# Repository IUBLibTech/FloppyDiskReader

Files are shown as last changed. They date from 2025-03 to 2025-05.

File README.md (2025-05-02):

# FloppyDiskReader
Hardware and Software for the BDPL Floppy Disk Reader

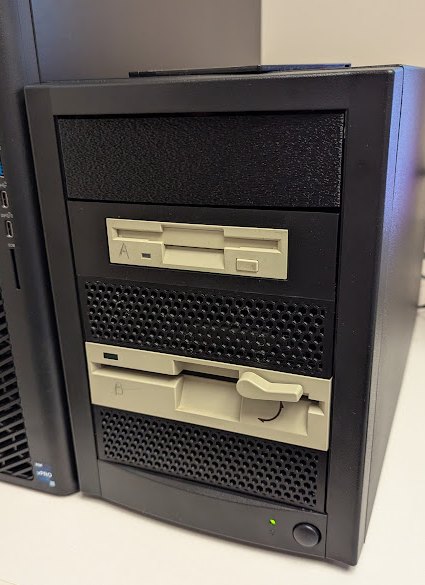
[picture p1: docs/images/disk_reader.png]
FloppyDisk Reader


## Hardware

The parts needed to build a reader from scratch are detailed in 
[Bill Of Materials](docs/bill_of_materials.md) and as of 2025 the cost is as little as $215 
using existing drives or $310 when buying eBay drives.

Assembly is described [here](docs/assembly.md)

## Software

The software is a Python / Qt application described [here](docs/software.md) 
and should run on most unix-y platforms, and maybe Windows (untested)

## License
Unless otherwise specified, all files are Copyright 2025 Trustees of Indiana 
University and are licensed under the Apache 2.0 License.

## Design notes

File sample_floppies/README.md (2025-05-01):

# Sample Floppy Disk Images
These are images which can be written to real floppies for testing.  

Each floppy is empty with the exception of some small sample data, such as
a basic program or text file.

The actual process will vary based on your hardware configuration, but
this should get you started.

The WRITE-ENABLE jumper must be present on the greaseweazle.

NOTE:  Writing 5.25" DD disks in an HD drive is not advised because of the
magnetic characteristics of the media.

Activate the Python Virtual Environment so the greaseweazle software is
in the path:

```
source .venv/bin/activate
```

Erase the disk.  If you are using a 40-track drive you will need to specify
which tracks to erase:

```
gw erase --drive A --tracks c=0-39
```

You may need to reset the greaseweazle if it's lost the index marker:

```
gw reset
```

Write the disk, specifying the format:
```
gw write --drive A --format commodore.1541 commodore_1541.d64
```

Generally the filenames are the greasweazle format name, substituting the '_'
with a '.'.

However, `ibm_1440_mac.img` is an `ibm.1440` formatted disk (flux-wise) but has
a Macintosh HFS filesystem on it, which is a normal configuration.

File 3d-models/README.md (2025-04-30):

# 3D models
These are the 3d models used for this project

* 5.25-bay-cover-vented.3mf - a drive bay blank
* Greaseweazle_Tray-HoleTest.stl - Test object to verify screws work
* Greaseweazle_Tray-Tray.{3mf,stl} - A full height 5.25" tray for mounting a V4.1 Greaseweazle
* Greaseweazle-4_Tray.* - A low-profile tray used to mount a V4 greaseweazle in the prototype
* USBC-Bulkhead - Mounting plate for USB C bulkhead connector

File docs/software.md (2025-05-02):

# Software

## Installation

Installation for this software should be pretty straightforward: it's a python
application running in a virtual environment.  It's been tested on Python 3.10
and 3.13

In the directory create the virtual environment and install the dependencies:

```
python3 -m venv .venv
. .venv/bin/activate
pip install -r requirements.txt
```

If successful, then the application can be started by running the `FloppyDiskReader`
shell script.

## Hardware Setup

Connect the floppy reader hardware to your computer using a USB cable.  When
the reader is powered on it will show up as a USB device called `generic greaseweazle`

You can verify this by running `lsusb`.

## Configuring the software

Copy the `FloppyDiskReader.conf.sample` file to `FloppyDiskReader.conf`.  That
is a basic configuration and should work in most cases where Drive A is a 3.5" 
HD floppy drive and B is a 5.25" HD drive.  

If necessary modify the configuration to meet your needs.  The file format is
YAML so aligning with spaces is important.

Linux permisions may block access to the greaseweazle.  To grant permission to
a user, become root and add them to the `dialout` group.  The user will need to
log out and log back in for the group changes to take effect.

## Running the software

The software can be started by running FloppyDiskReader.  If it is able to 
connect to the greaseweazle it will display the main window:

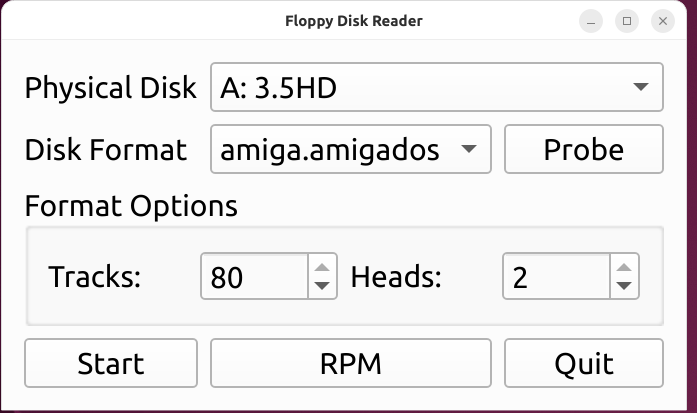
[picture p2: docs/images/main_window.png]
Main Window


The controls are:
* Physical disk selects which drive should be used for the read
* Disk format dropdown indicates what format should be read
* Probe button will try to determine the type of disk installed in the physical disk
* Format options allow control of number of tracks and number of heads
* Start button will start a new disk read
* RPM will test the RPM of the selected disk drive 
* Quit exits the program.

### Testing Disk RPM
Normally this isn't needed but it is a good way to verify the greaseweazle is
operating correctly.  Place a disk in the drive and hit the RPM button.  

If things are working it will show the expected RPM and the actual spin rate.

### Probing the format
Sometimes it's impossible to know what kind of disk you have.  The disk probe
will read track 1 of all of the configured format types and show you the ones
that it thinks are applicable.  The most likely candidate is the default:

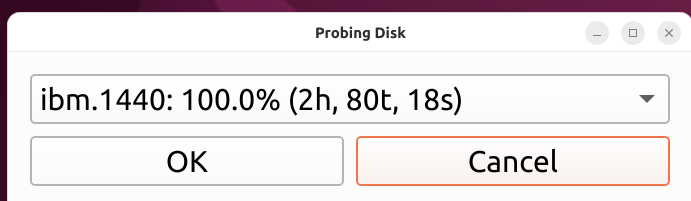
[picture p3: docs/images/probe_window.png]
Disk Probe


The percentage shown is the amount of expected sectors it was able to read. 
This number may be less than 100% if the disk has errors.

Some formats may be indistinguisable from each other.  For example, when probing
a 360K PC floppy (9 sectors per track), if the rare 320K (8 sectors per track)
floppy format is added to the list of formats to probe both will show 100%, 
but internally when using the 320K format it'll complain that it found an extra
sector on the track that was ignored.  The list is sorted by largest format
first, so that will likely be the correct format if there is ambiguity.

Select OK to use that format, cancel to manually select.

NOTE:  This is the physical format on the disk - the configuration of the
magnetic flux.  Macintosh 1.44M floppies will show up as `ibm.1440` because
the physical format is the same as the IBM 1.44M format even though the filesystem
data on there is different (HFS vs FAT16)

### Format Options
Normally this will not be needed unless you are wanting to read a partial disk.

One notable exception to this is for the `commodore.1541` format.  The format
allows for 40 tracks but the normal format was 35.  When reading these disks
one would adjust it down to 35 tracks.

### Reading a disk
Once the drive and format are selected and any adjustments are made to the format,
then pressing the Start button will read the disk.

A file dialog will allow you to choose where to save the disk image and the 
extension should be automatically selected.  Once selected, a read window
will pop up:

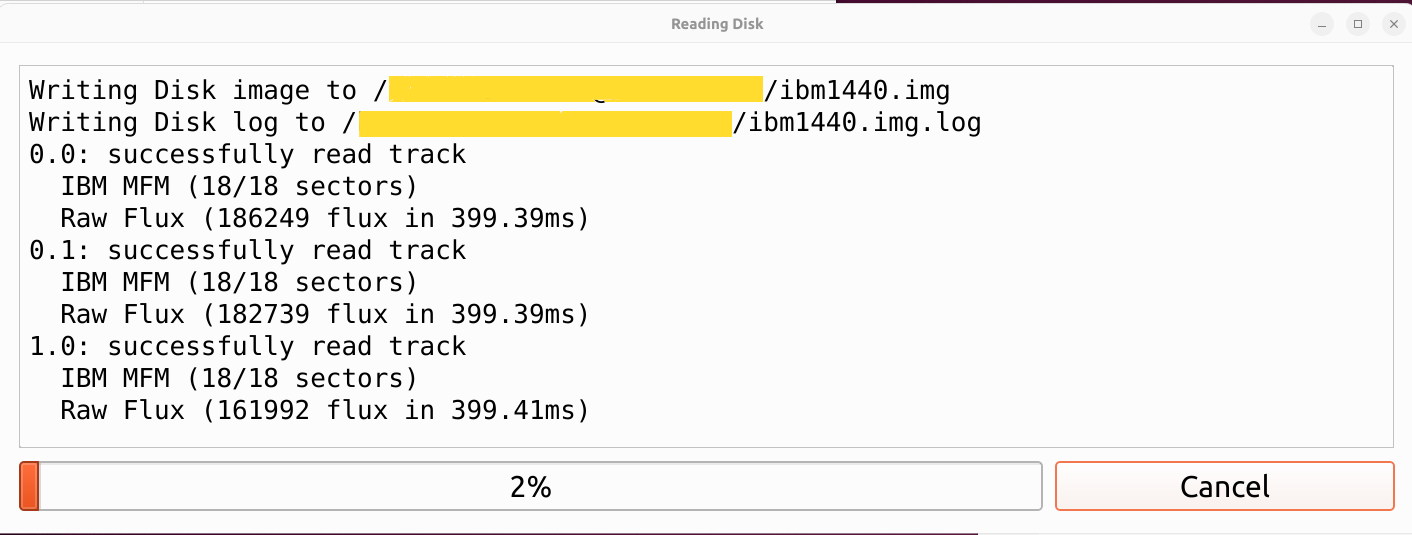
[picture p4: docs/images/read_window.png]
Read Window


This is a running log of the disk read and will be stored in a file that has 
the same name as the disk image with `.log` appended to it.

#### Read errors
If there are any read errors the track will be retried and if it still fails
the bad sector will be filled with the text `-=[BAD SECTOR]=-` to maintain
alignment.

The log will note that there were read failures at the end to alert the operator

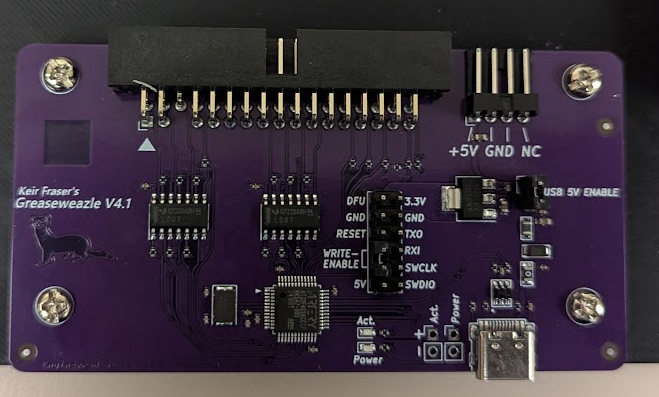
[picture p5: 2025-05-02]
docs/images/gw41_as_shipped.png

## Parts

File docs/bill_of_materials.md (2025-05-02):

# Bill of Materials

This is a list of the parts needed to build a device from scratch.  

These are parts/sources from early 2025 and may vary as time moves forward...

## Purchased Parts
* Greaseweazle 4.1	Floppy Flux → USB Adapter (1x)
    * Emmy Bear Retro Computing  (US)
      
      https://www.ebay.com/itm/255252124132
      
      Mansion of Maniacs / Fat / Fully Assembled / Deluxe
    
      $38.96 + $7.80 Shipping + Tax → $58.31US

    * Decromancer (CA)    
    
      https://decromancer.ca/greaseweazle/
    
      $36.50 CAD + $11.76 CAD Shipping → $34.01 US

    * Retro-Updates.com (NL)
    
      https://www.retro-updates.com/product/12383903/greaseweazle-v4-1-usb-floppy-adapter-flux-reader-writer
      
      Device + case only, no cables
      
      €29.50 + €14.50 shipping → $46.06 US

* Enclosure	(1x)
    DupliM External 5-Bay Duplicator Case Enclosure Tower for DVD CD Blu-ray HDD USB - Includes UL Power Supply

    https://www.amazon.com/DupliM-External-Duplicator-Enclosure-Blu-ray/dp/B0DK7RJJ3T	$120

* 5v Power Cable (1x)
  3 Pack Floppy Drive to Sata Adapter 15 PIN SATA Male to 4 PIN FDD Female Power Supply Cable Converter 15pin to 4pin Connector for Mini PC DIY Hard Disk Bay Computer Dock Sound Card Miner Mining

  Connects case power supply SATA power cables to 4-pin floppy connector.

  Need two cables, one for the 3.5" drive and one for the greaseweazle
	
  https://www.amazon.com/ThtRht-SATA-Power-Cable-Converter/dp/B0D5LH7SFY  $7
  
* USB-C  panel mount	
  
  Extend the Greaseweazle USB-C port to the back panel, 1ft
	
  https://www.amazon.com/AAOTOKK-3-1Panel-Adapter-Supports-Charging/dp/B08HS6X44P $10

* Floppy data cable	
  
  CablesOnline 24-inch Universal Floppy Drive Ribbon Cable for 3.5 or 5.25in Drives, FF-001

  Connect both floppy drives to the greaseweazle

  https://www.amazon.com/CablesOnline-24-inch-Universal-Floppy-Ribbon/dp/B07KDJTMGP $12

* 3.5" bay adapter	

  StarTech.com 3.5" to 5.25" Front Bay Mounting Bracket w/ Mounting Screws (BRACKETFDBK),Black

  mount a 3.5" disk into a 5.25" hole

  https://www.amazon.com/StarTech-com-3-5in-5-25in-Bracket-Adapter/dp/B000HLZXH2  $6

* Screws	

  502PCS Computer Screws Assortment Kit, Motherboard Standoffs Screws PC Screws for PC Fan, PC Case, HDD Hard Drive, Laptop, SSD, CD-ROM, Used for DIY Installation & Repair of Computer Parts

  We'll need a bunch of misc screws to put this together.  Included for completeness in case someone else is starting from scratch.  I'll likely buy this set for myself and then donate the screws for this. 
	
  https://www.amazon.com/Bemaka-Assortment-Motherboard-Standoffs-Installation/dp/B0CZDNZGR9 $10

  The storage enclosure specified above contains the necessary screws

## 3d Printed Parts

There are some things that are either very hard to find or are custom to this 
project.  The filament total is less than 1Kg so the materials price is less 
than $20.  However, the price for printing varies.  In our case it'll be $0 
because I'll print it on my printers, but if others were to replicate this, 
it might have a cost.

The bulkhead adapter and greaseweazle tray were designed in FreeCAD and if
different dimensions are needed the values in the spreadsheet in the model
files can be adjusted.

* Drive Blank (2x)
  
  Needed to cover the holes in the unused bays of the case
  
  https://www.printables.com/model/408472-pc-525-drive-blanks-vents-drive-mount-handlepocket/files

  Creative Commons 4.0 Attribution - Noncommercial - Share Alike

  The file is `5.25-bay-cover-vented.3mf`

* USB Bulkhead Adapter (1x)

  Place to mount the USB C extension table on the back of the enclosure
        
  Designed in house

* Greaseweazle mount tray (1x)
  
  Place to mount the Greaseweazle, also serves as the drive blank for the 3rd unused bay
  
  Designed in house.

  This tray is `Greaseweazle_Tray-Tray.3mf`.   

  There is also a longer variant if needed.

## Disk Drives

The above assumes we have floppy drives sitting around.  However, if we want to get "new" drives
* 5.25" Floppy Drive	TEAC FD-55GFR	$50 - $120
* 3.5" Floppy Drive	TEAC FD-235HF  (new old stock)	$40 - $60

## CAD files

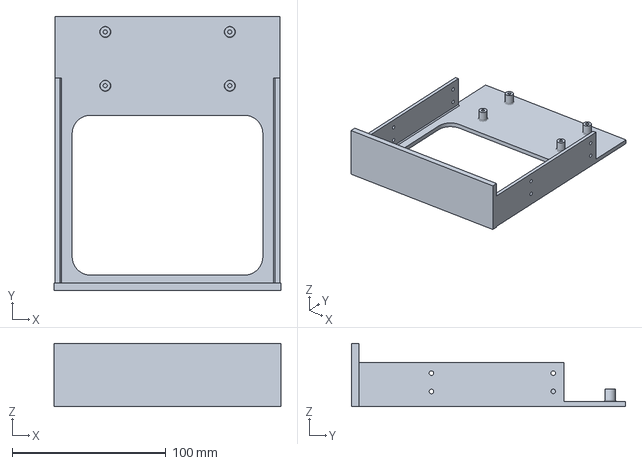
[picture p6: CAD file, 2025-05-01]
3d-models/Greaseweazle_Tray-Longer-Tray.3mf
147.5 x 178.2 x 41.3 mm

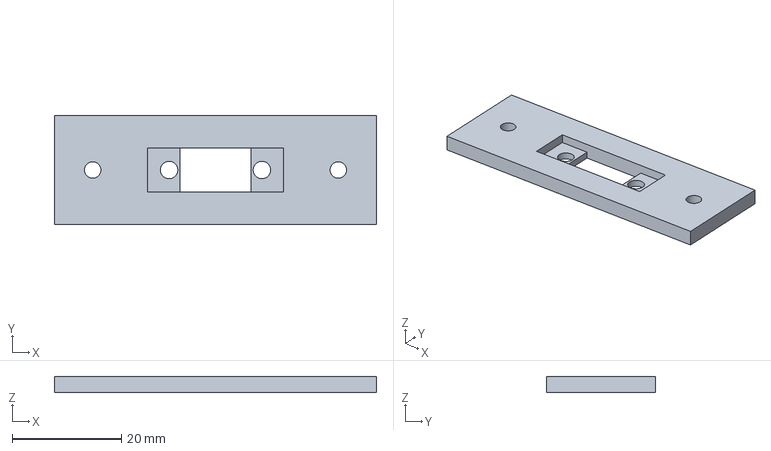
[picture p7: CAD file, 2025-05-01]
3d-models/USBC-Bulkhead.FCStd
59.0 x 20.0 x 3.00 mm

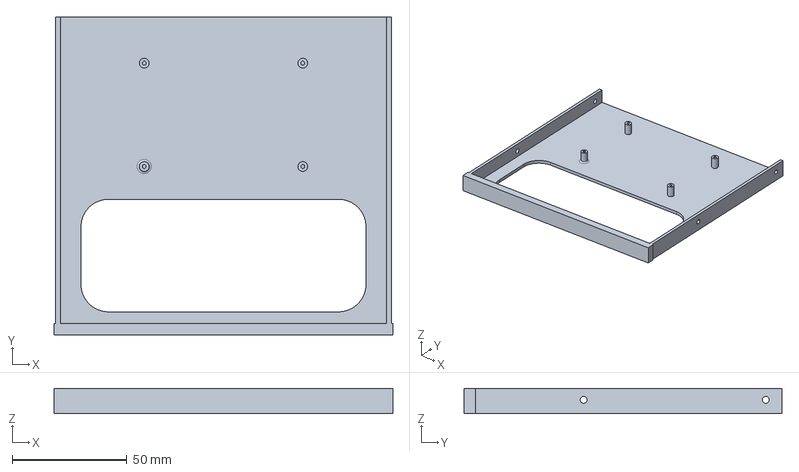
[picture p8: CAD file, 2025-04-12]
3d-models/Greaseweazle-4_Tray.FCStd
147.5 x 138.2 x 11.0 mm

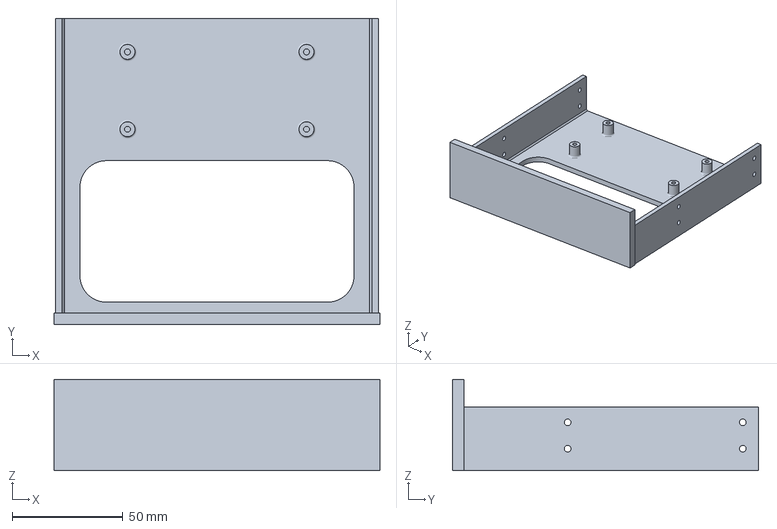
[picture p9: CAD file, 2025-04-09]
3d-models/Greaseweazle_Tray-Tray.3mf
147.5 x 138.2 x 41.3 mm

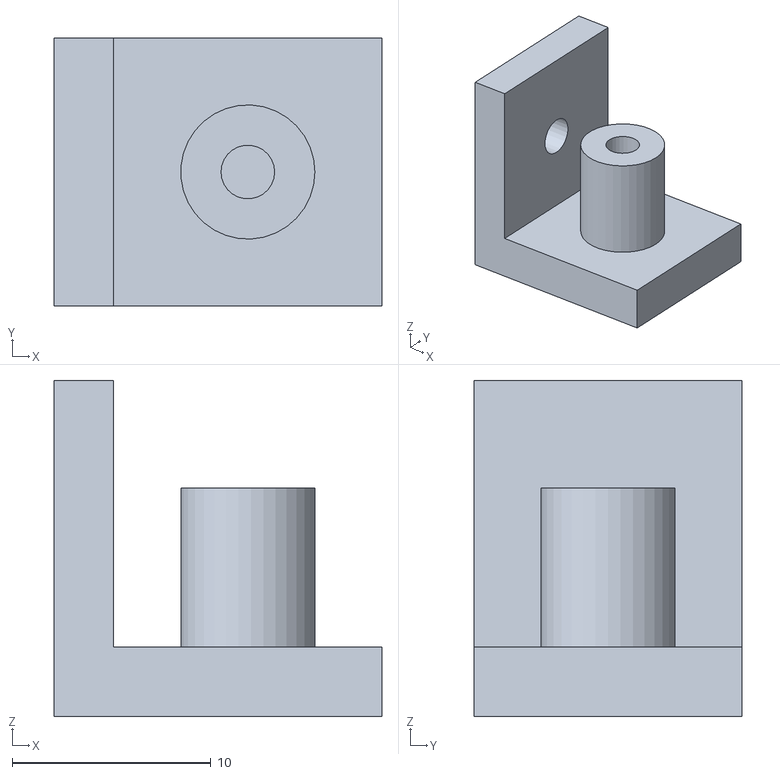
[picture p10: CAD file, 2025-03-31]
3d-models/Greaseweazle_Tray-HoleTest.stl
16.5 x 13.5 x 16.9

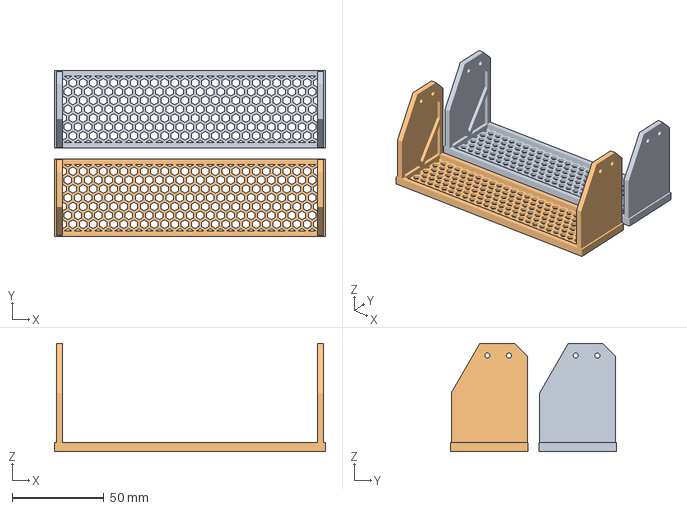
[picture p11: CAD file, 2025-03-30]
3d-models/5.25-bay-cover-vented.3mf
148.0 x 90.6 x 59.0 mm
5.25-bay-cover-vented.stl x 2

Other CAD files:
3d-models/Greaseweazle_Tray.FCStd
3d-models/Greaseweazle-4_Tray-Tray.stl
3d-models/Greaseweazle_Tray-Longer-Tray.stl
3d-models/Greaseweazle_Tray-Tray.stl
3d-models/USBC-Bulkhead.3mf
3d-models/USBC-Bulkhead.stl

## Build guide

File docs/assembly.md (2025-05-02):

# Assembly

### Disk Drives

Mount the disk drives in the enclosure in a way that is most convenient.  If you have 
two disk drives you will likely want to put drive A above drive B.  The drive letter is 
assigned based on where it is connected to the cable.  The single connector after the 
twist on the data cable will be drive A and the one between the twist and the 
connector at the end of the cable will be drive B. 

It may make sense to install the data cable on the drives temporarily to help determine
the best organization for the drives.

Each drive installed will need both a power cable and a data cable.

The power cables will only fit in one orientation.  You may need power adapters
to get the correct connectors for your enclosure and drives.

Some data cables do not have notches to force a specific orientation so make 
sure pin 1 is connected correctly.

On the cable pin 1 is usually indicated by a red stripe on the edge of the 
ribbon.

On the disk drive pin 1 is usually indicated by a triangle/arrow or a 1.  If 
pin 34 is indicated on the drive then pin 1 is on the other end.

If any data cables are inserted upside down the device will not work and when
powered on the drive lights will stay on.

### USB Bulkhead

A USB extension cable is connected to a bulkhead adapter and then the adapter
is mounted to the case.

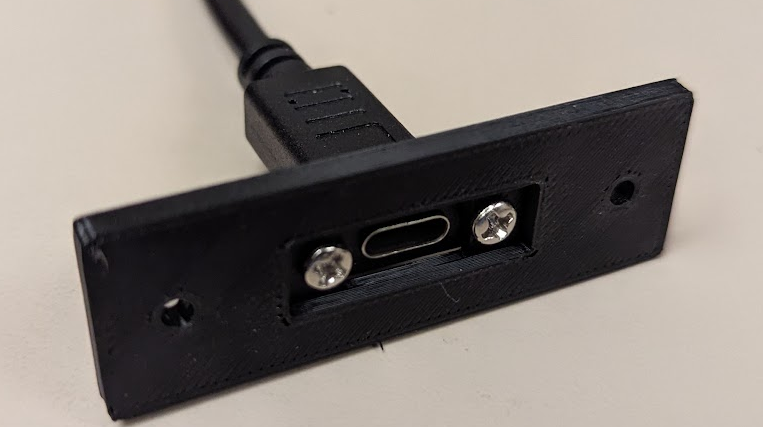
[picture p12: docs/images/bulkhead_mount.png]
Bulkhead connector


### Greaseweazle

Two jumpers will need to be changed to configure the Greaseweazle:
* USB 5V ENABLE - this will allow the device to be powered by the enclosure
* WRITE-ENABLE - this will block writes to the floppy drives

In both of these cases the jumpers need to be removed.  Optionally, instead of removing
the jumpers they can be placed at a 90 degree angle and connected to only one pin.

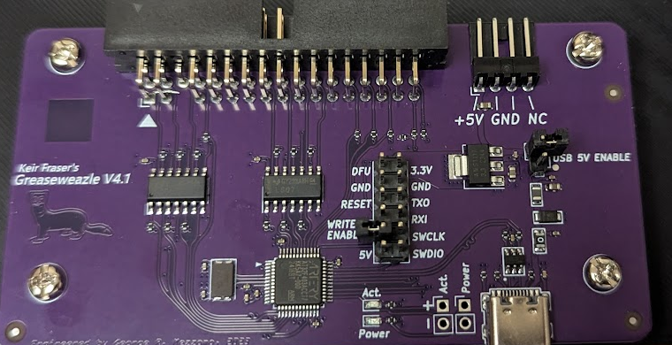
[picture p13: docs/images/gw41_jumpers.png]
Jumpers set correctly


The greaseweazle will be mounted to the 3d-printed tray using whatever screws from the PC
kit that are convenient.  The tray itself will be mounted into the enclosure the same way
the drives were.

Three cables will need to be connected to the greaseweazle:  usb, power, and
data.

The USB port on the greaseweazle will be connected to the extension cable from
the bulkhead connector.  If the cable is too short then the longer greaseweazle
tray may be needed.

The power cable will only fit one way and depending on the enclosure you may
need some adapters to get the right plug.

As with the floppy drives, the data cable should be oriented so pin 1 on the
cable is aligned with pin 1 on the greaseweazle.  On the greaseweazle, pin 1
is indicated by an arrow on the circuit board and on the connector itself.

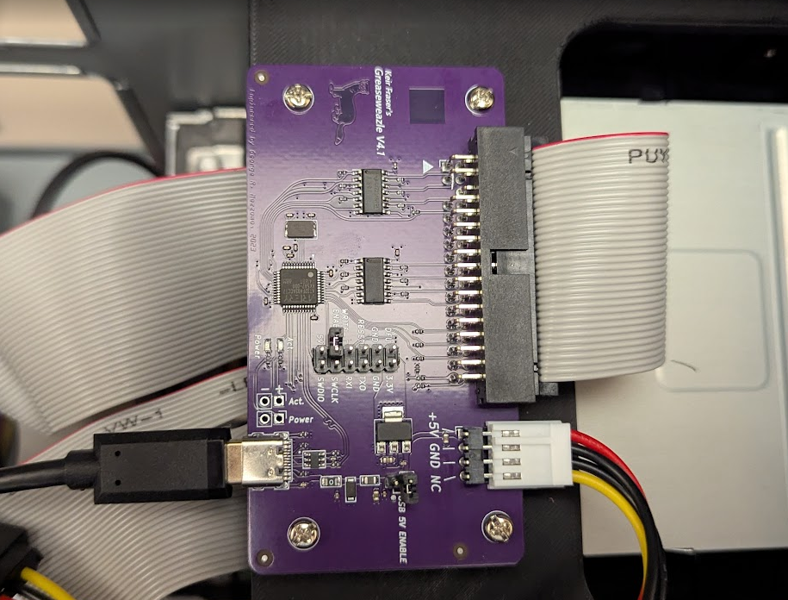
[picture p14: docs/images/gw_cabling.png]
Greaseweazle cabling


### Drive Blanks
Any left over drive bays can have drive blanks mounted.

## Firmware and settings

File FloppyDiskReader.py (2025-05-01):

#!/bin/env python3
import argparse
import logging
from pathlib import Path
import signal
import sys

from floppy import FloppyReader, codec
from PySide6.QtWidgets import *
from PySide6.QtGui import *
from PySide6.QtCore import *

floppy: FloppyReader = None

def main():
    global floppy
    signal.signal(signal.SIGINT, lambda signal, handler: QApplication.closeAllWindows)  # doesn't work.
    app = QApplication(sys.argv)
    parser = argparse.ArgumentParser()
    parser.add_argument("--config", default=Path(sys.path[0], "FloppyDiskReader.conf"), type=Path, help="Configuration file")
    parser.add_argument("--debug", default=False, action="store_true", help="Enable debug logging")
    args = parser.parse_args()
    logging.basicConfig(level=logging.DEBUG if args.debug else logging.INFO)

    try:
        if not args.config.exists():
            x = QMessageBox(QMessageBox.Icon.Critical, "Missing Config", f"The configuration file\n'{args.config.absolute()}'\n doesn't exist.")
            x.setModal(True)        
            x.show()
            app.exec()
            exit(1)

        try:
            floppy = FloppyReader(args.config)    
        except Exception as e:
            x = QMessageBox(QMessageBox.Icon.Critical, "Greaseweazle Error", f"Cannot connect to the greaseweazle:\n'{e}'")
            x.setModal(True)        
            x.show()
            app.exec()
            raise(e)
            
        window = MainWindow()
        window.show()
        return app.exec()

    except Exception as e:
        logging.exception(e)
        exit(2)


class MainWindow(QWidget):
    def __init__(self):
        super().__init__()
        self.setWindowTitle("Floppy Disk Reader")
        layout = QGridLayout()
        
        # physical disk
        self.pdisk = QComboBox()
        for k, v in floppy.drives.items():
            self.pdisk.addItem(f"{k}: {v['type']}", k)
        self.pdisk.setCurrentIndex(0)
        layout.addWidget(QLabel("Physical Disk"), 0, 0)  
        layout.addWidget(self.pdisk, 0, 1, 1, -1)
        
        # disk format
        self.format = QComboBox()
        def refresh_formats():
            self.format.clear()
            for k, v in floppy.get_formats_for_drive(self.pdisk.currentData()).items():
                self.format.addItem(k, v)
        refresh_formats()
        self.pdisk.currentIndexChanged.connect(refresh_formats)
        layout.addWidget(QLabel(text="Disk Format"), 1, 0)
        layout.addWidget(self.format, 1, 1)
        
        probe = QPushButton("Probe")
        def do_probe():
            probewindow = ProbeWindow(self.pdisk.currentData())
            #probewindow.setParent(self)
            probewindow.show()
            probewindow.probe()
            probewindow.exec()
            res = probewindow.result()
            if res == QMessageBox.StandardButton.Ok:
                fmt = probewindow.format_name
                self.format.setCurrentIndex(self.format.findText(fmt))
        probe.pressed.connect(do_probe)
        layout.addWidget(probe, 1, 2)
        
        # tracks and parameters
        gbox = QGroupBox("Format Options")
        glayout = QGridLayout()
        self.tracks = QSpinBox(minimum=1, singleStep=1, value=40)
        self.heads = QSpinBox(minimum=1, singleStep=1, value=2)
        def refresh_tracks_and_heads():
            fmt: codec.DiskDef = self.format.currentData()
            if fmt:
                self.tracks.setMaximum(fmt.cyls)
                self.tracks.setValue(fmt.cyls)
                self.heads.setMaximum(fmt.heads)
                self.heads.setValue(fmt.heads)
        refresh_tracks_and_heads()
        self.format.currentIndexChanged.connect(refresh_tracks_and_heads)
        glayout.addWidget(QLabel("Tracks:"), 0, 0)
        glayout.addWidget(self.tracks, 0, 1)
        glayout.addWidget(QLabel("Heads:"), 0, 2)
        glayout.addWidget(self.heads, 0, 3)

        gbox.setLayout(glayout)
        layout.addWidget(gbox, 2, 0, 1, -1)

        read = QPushButton("Start")
        def do_read():
            readwindow = ProcessWindow(self.pdisk.currentData(), 
                                        self.format.currentText(), self.format.currentData(),
                                        self.tracks.value(), self.heads.value())
            #readwindow.setParent(self)
            readwindow.show()
            readwindow.read()
            readwindow.exec()
        read.pressed.connect(do_read)
        layout.addWidget(read, 3, 0)

        rpm = QPushButton("RPM")
        def check_rpm():
            dlg = QMessageBox(parent=self,
                              icon=QMessageBox.Icon.Information)
            dlg.setWindowTitle("Disk RPM")
            try:
                rpm = floppy.rpm(self.pdisk.currentData())
                nom_rpm = floppy.drives[self.pdisk.currentData()]['rpm']
                rate = 100 * (rpm / nom_rpm)
                dlg.setText(f"Drive Speed:\nMeasured {rpm:0.2f} RPM\nNominal {nom_rpm} RPM\nDrift {100 - rate:0.2f}%")                
            except Exception as e:                
                dlg.setText(f"Error: {e}")
                dlg.setIcon(QMessageBox.Icon.Critical)
            dlg.setModal(True)
            dlg.show()

        rpm.pressed.connect(check_rpm)
        layout.addWidget(rpm, 3, 1)
        
        quit = QPushButton("Quit")
        quit.pressed.connect(QCoreApplication.quit)
        layout.addWidget(quit, 3, 2)
        self.setLayout(layout)


class ProbeWindow(QDialog):
    def __init__(self, drive: str):
        super().__init__()
        self.setWindowTitle("Probing Disk")
        self.setModal(True)
        self.drive = drive
        self.format_name = None
        self.result_value = None
        layout = QGridLayout()
        
        self.format = QComboBox()
        self.format.setFixedWidth(40 * 8)
        self.format.addItem("Probing...")
        layout.addWidget(self.format, 0, 0, 1, -1)
        
        self.ok = QPushButton("OK")    
        def ok_func():
            self.result_value = QMessageBox.StandardButton.Ok
            self.format_name = self.format.currentData()
            self.close()
        self.ok.pressed.connect(ok_func)
        layout.addWidget(self.ok, 1, 0)

        self.cancel = QPushButton("Cancel")
        def cancel_func():
            self.result_value = QMessageBox.StandardButton.Cancel
            self.close()
        self.cancel.pressed.connect(cancel_func)
        layout.addWidget(self.cancel, 1, 1)
        self.setLayout(layout)
        self.adjustSize()

    def probe(self):
        # turn off the buttons
        self.ok.setDisabled(True)
        self.cancel_probe = False
        def do_cancel_probe():
            self.cancel_probe = True
        self.cancel.pressed.connect(do_cancel_probe)
        self.format.setDisabled(True)
        QGuiApplication.processEvents()
        
        def callback(x):
            self.format.setItemText(0, f"{x['message']} ({100*x['progress']:0.2f}%)")
            QGuiApplication.processEvents()
            return self.cancel_probe

        items = floppy.probe(self.drive, callback=callback)
        if self.cancel_probe:
            return
        
        if not items:
            self.format.setItemText(0, "No Formats Found")
        else:
            self.format.clear()
            # sort these by largest percentage and then largest size.
            for t, d in  [(f"{x}: {items[x][0]:0.1f}% ({items[x][1]}h, {items[x][2]}t, {items[x][3]}s)", x) for x in sorted(items.keys(), key=lambda x: items[x], reverse=True)]:
                self.format.addItem(t, d)
            self.ok.setDisabled(False)
            self.format.setDisabled(False)
            

    def result(self):
        return self.result_value


class ProcessWindow(QDialog):
    def __init__(self, drive: str, format_name: str, format: codec.DiskDef, tracks: int, heads: int):
        super().__init__()
        self.setWindowTitle("Reading Disk")
        self.drive = drive
        self.format_name = format_name
        self.format = format
        self.tracks = tracks
        self.heads = heads
        self.image_file: Path = None
        self.log_file: Path = None
        self.cancel_read = False
        logging.info(f"{drive}, {format_name}, {format}, {tracks}, {heads}")

        layout = QGridLayout()
        self.results = QPlainTextEdit()
        self.results.setLineWrapMode(QPlainTextEdit.LineWrapMode.NoWrap)
        self.results.setWordWrapMode(QTextOption.WrapMode.NoWrap)
        courier = QFont("courier", 10)
        metrics = QFontMetrics(courier)
        self.results.setFont(courier)
        self.results.setReadOnly(True)
        self.results.setLineWidth(86)
        self.results.setFixedWidth(86 * metrics.averageCharWidth())

        self.results.adjustSize()
        layout.addWidget(self.results, 0, 0, 1, -1)

        self.progress = QProgressBar(maximum=100, value=0, textVisible=True)
        layout.addWidget(self.progress, 1, 0, 1, 3)

        self.closebtn = QPushButton("Cancel")
        def do_cancel_read():
            self.cancel_read = True    
        self.closebtn.pressed.connect(do_cancel_read)
        layout.addWidget(self.closebtn, 1, 3)

        self.setLayout(layout)
        self.adjustSize()

        self.setModal(True)

    def read(self):
        ext = floppy.get_extension_for_format(self.format_name)
        
        def file_selected(filename):
            self.image_file = filename
        
        fdlg = QFileDialog(caption="Save Disk Image As...",
                           defaultSuffix=ext,                           
                           filter=f"Disk Image *{ext}(*{ext})",
                           acceptMode=QFileDialog.AcceptMode.AcceptSave,                           
                           )
        fdlg.fileSelected.connect(file_selected)
        fdlg.exec()        
        QGuiApplication.processEvents()
        if self.image_file:
            self.image_file = Path(self.image_file)
            self.log_file = self.image_file.parent / ((self.image_file.name) + ".log")            
            self.results.appendHtml(f"<pre>Writing Disk image to {self.image_file}</pre>")
            self.results.appendHtml(f"<pre>Writing Disk log to {self.log_file}</pre>")
            self.has_errors = False
            with open(self.log_file, "w") as f:
                def do_log(message):
                    msg = f"{message['logical_cylinder']}.{message['head']}: {message['message']}\n  {message['dat']}\n  {message['flux']}\n"
                    self.results.appendHtml(f"<pre>{msg}</pre>")
                    f.write(msg)
                    cursor = self.results.textCursor()
                    cursor.movePosition(QTextCursor.MoveOperation.End)
                    cursor.movePosition(QTextCursor.MoveOperation.StartOfLine)
                    self.results.setTextCursor(cursor)


                def track_callback(message):
                    self.progress.setValue(message['progress'] * 100)
                    if not message['success']:
                        self.has_errors = True
                    do_log(message)
                    QGuiApplication.processEvents()
                    return self.cancel_read
            
                floppy.read_image(self.drive, self.format_name, self.image_file, 0, self.tracks, 0, self.heads, callback=track_callback)

                if self.has_errors:
                    self.results.appendHtml(f"<pre>The disk had read errors, review the log</pre>")
                else:
                    self.results.appendHtml(f"<pre>The disk was read successfully</pre>")


            self.closebtn.setText("Close")
            self.closebtn.pressed.connect(self.close)


if __name__ == "__main__":
    main()

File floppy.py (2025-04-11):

#!/bin/env python3
from typing import Callable, Tuple
from greaseweazle.tools import util
from greaseweazle import error
from greaseweazle import usb as USB
from greaseweazle.flux import Flux, HasFlux
from greaseweazle.codec import codec
from greaseweazle.codec.codec import DiskDef_File
from greaseweazle.image import image
from greaseweazle import track
import logging
from pydantic import BaseModel, Field, field_validator
import sys
import yaml


drive_params = {
    '5.25DD': {'tracks': 40, 'heads': 2, 'rpm': 300},
    '5.25HD': {'tracks': 80, 'heads': 2, 'rpm': 360},
    '3.5DD': {'tracks': 80, 'heads': 2, 'rpm': 300},
    '3.5HD': {'tracks': 80, 'heads': 2, 'rpm': 300}
}


class FloppyReaderConfig(BaseModel):
    """
    Structure of the configuration file
    """
    class GreaseWeazleConfig(BaseModel):
        port: str = Field(default="auto")
        drives: dict[str | int, str] = Field(default_factory=dict)

        @field_validator('drives')
        @classmethod
        def check_drives(cls, value: dict):
            new = {}
            for k, v in value.items():
                nk = str(k).upper()
                if nk not in ('0', '1', '2', 'A', 'B'):
                    raise ValueError("Drive letter must be 0, 1, 2, A, or B")
                nv = v.upper()
                if nv not in drive_params.keys(): 
                    raise ValueError(f"Drive Type must be one of: {list(drive_params.keys())}")
                new[nk] = nv            
            return new

    greaseweazle: GreaseWeazleConfig
    
    formats: dict[str, list[list[str] | str]]

    @field_validator('formats')
    @classmethod
    def check_formats(cls, value: dict):
        new = {}
        for k, v in value.items():
            nk = k.upper()
            if nk not in drive_params.keys():
                raise ValueError(f"Drive Type must be one of: {list(drive_params.keys())}")
            nv = []
            for x in v:
                if isinstance(x, list):
                    nv.extend(x)
                else:
                    nv.append(x)
            # make sure each of the formats are actually supported by the greaseweazle
            all_formats = codec.get_all_formats('', DiskDef_File(None))
            for x in nv:
                if x not in all_formats:
                    raise ValueError(f"Format {x} not supported")
        
            new[nk] = nv
        return new


class FloppyReader:
    def __init__(self, config):
        with open(config) as f:
            self.config = FloppyReaderConfig(**yaml.safe_load(f))

        # connect to the greaseweazle        
        port = self.config.greaseweazle.port
        self.gw: USB.Unit  = util.usb_open(None if port=='auto' else port)

        # get the drive devices for everything..
        self.drives: dict[str, util.Drive] = {}
        for d, t in self.config.greaseweazle.drives.items():
            self.drives[d] = {
                'type': t,
                **drive_params[t],
                'drive': util.Drive()(d)
            }

        self.extension_map = {}        
        for suffix in util.image_types:
            iclass = util.get_image_class('x' + suffix)
            if iclass.default_format:
                self.extension_map[iclass.default_format] = (suffix, iclass)



    def use_drive(self, function, drive: str, *args, motor: bool = True, **kwargs):
        """Select the drive, optionally turn on the motor, and then run the function
        The function will be called with these arguments:
        function(the greaseweazle, the drive, *args, **kwargs)        
        """
        if drive not in self.drives:
            raise KeyError("This drive is not configured")
        
        drv: util.Drive = self.drives[drive]['drive']        
        self.gw.set_bus_type(drv.bus.value)        
        res = None
        try:
            self.gw.drive_select(drv.unit_id)
            self.gw.drive_motor(drv.unit_id, motor)
            res = function(self.gw, drv, *args, **kwargs)
        except KeyboardInterrupt:
            self.gw.reset()
            raise
        finally:
            self.gw.drive_motor(drv.unit_id, False)
            self.gw.drive_deselect()
        return res


    def reset(self):
        """Reset the greaseweazle"""
        self.gw.reset()


    def rpm(self, drive: str) -> float:
        """Get the RPM of the drive when there's a disk in there"""
        def measure_rpm(gw: USB.Unit, drv: util.Drive, *args):
            gw.seek(0, 0)
            flux = gw.read_track(1)
            tpr = flux.index_list[-1] / flux.sample_freq
            return 60 / tpr
        r = self.use_drive(measure_rpm, drive, motor=True)
        return r


    def get_formats_for_drive(self, drive: str) -> dict[str, codec.DiskDef]:
        """Get a list of the formats supported for that drive"""
        return {f: codec.get_diskdef(f) for f in self.config.formats.get(self.drives[drive]['type'], [])}
        

    def probe(self, drive: str, callback: Callable = None) -> dict[str, tuple[float, int]]:
        """Look at the drive and try to figure out what disk is in there
            We're going to do this by reading the first track and see if it works.
            We're not going to deal with the weird CP/M machines that had an FM
              track on 0, but MFM elsewhere.
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

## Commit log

2025-03-28 initial import
    [5.25-bay-cover-vented.3mf]
2025-03-30 initial greaseweazle mount
    [5.25-bay-cover-vented.3mf, Greaseweazle_Tray-Body.3mf, Greaseweazle_Tray-Body.stl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]
2025-03-31 fixed hole sizes, created hole test object
    [Greaseweazle_Tray-Body.3mf, Greaseweazle_Tray-Body.stl, Greaseweazle_Tray-HoleTest.stl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]
2025-03-31 updating model and ignoring freecad backups
    [Greaseweazle_Tray.FCStd]
2025-04-09 restructure, wrote rpm check
    [Greaseweazle_Tray-Tray.3mf]
2025-04-10 gui. probe & rpm
2025-04-12 stared bulkhead connector. including prototype tray
    [Bulkhead-Outer.3mf, Bulkhead.FCStd, Greaseweazle-4_Tray-Tray.stl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]
2025-04-30 usbC bulkhead panel, sample disk images
    [Bulkhead-Outer.3mf, Bulkhead.FCStd, USBC-Bulkhead.3mf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]
2025-05-01 increased the size of the USB port hole and recessed the connector a bit
    [USBC-Bulkhead.FCStd, USBC-Bulkhead.stl]
2025-05-01 added a longer tray since our enclosure is a little longer than I thought
    [Greaseweazle_Tray-Longer-Tray.3mf, Greaseweazle_Tray-Longer-Tray.stl, Greaseweazle_Tray.FCStd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]
2025-05-01 sample disks, startup script, more docs.
